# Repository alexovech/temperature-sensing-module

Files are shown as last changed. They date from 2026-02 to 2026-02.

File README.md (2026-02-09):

# Greenhouse Monitoring System – Temperature Sensing Module

Team of 4 students.  
My role: temperature sensing module design, multi-sensor integration, and 3D enclosure design.   
Designed and implemented an LM35-based temperature sensing module with analog signal conditioning, calibration, and hardware-level error detection.  
The project consists of two stages: a standalone temperature sensing module and system integration with enclosure.

---

## Overview

- **Full project description:** [Overview](docs/overview.md)
- **Skills Developed:** Designing operational amplifier circuit, sensor calibration and parameter identification, embedded system implementation in Arduino, 3D CAD modelling.
- **Features:** OpAmp-based gain and offset correction, Arduino ADC inverse mapping, sensor error detection, custom 3D-printed enclosure.
- **Technology:** Arduino, LM35 temperature sensor, LM741 operational amplifier, Resistors, OLED display, LEDs.
- **Simulation:** Analog part designed in [Multisim](schematic/multisim/Adder_with_divider_rule); Enclosure model designed in [Autodesk Fusion 360](schematic/cad).
- **Language:** C/C++ (Arduino).

---

# Stage 1 - Temperature Sensor

## Problem Statement

The LM35 temperature sensor provides a low-level output (~10 mV/°C).  
The Arduino ADC operates over a much higher voltage range: from 3 V to 5 V.  
Such a small sensor voltage results in poor ADC resolution and reduced measurement accuracy.  
To obtain valid and reliable temperature readings, the signal must be shifted and amplified into a suitable voltage range.  
This is achieved using LM741 operational amplifiers and resistive networks.

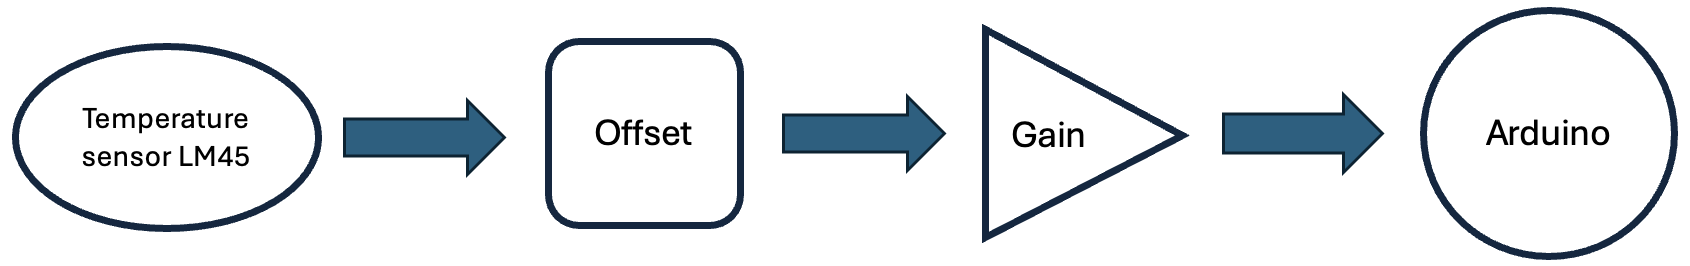
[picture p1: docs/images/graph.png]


## Design Demonstration

**Hardware Implementation**

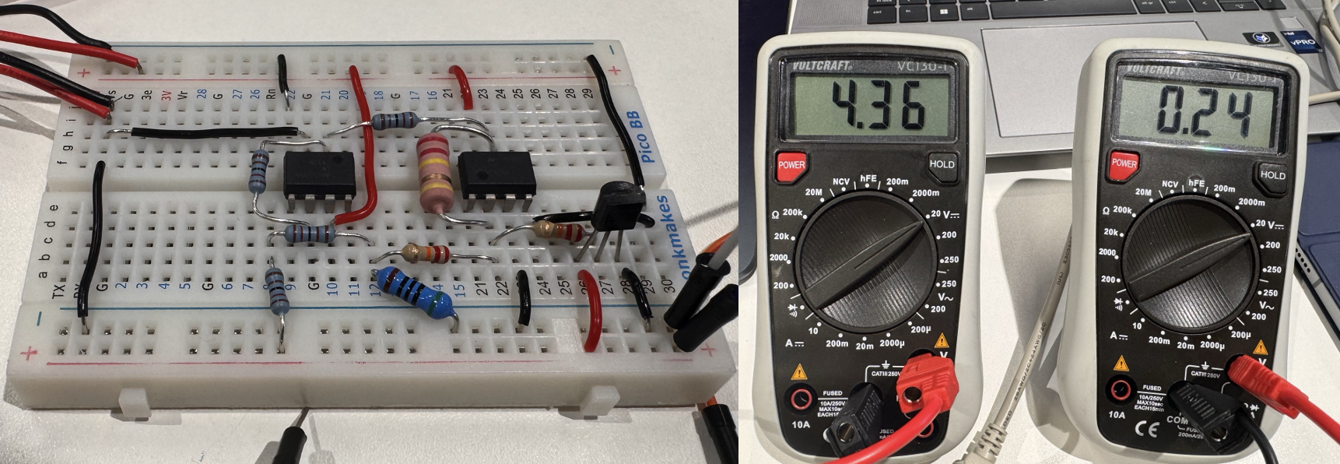
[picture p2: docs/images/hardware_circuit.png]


**Circuit in Multisim**

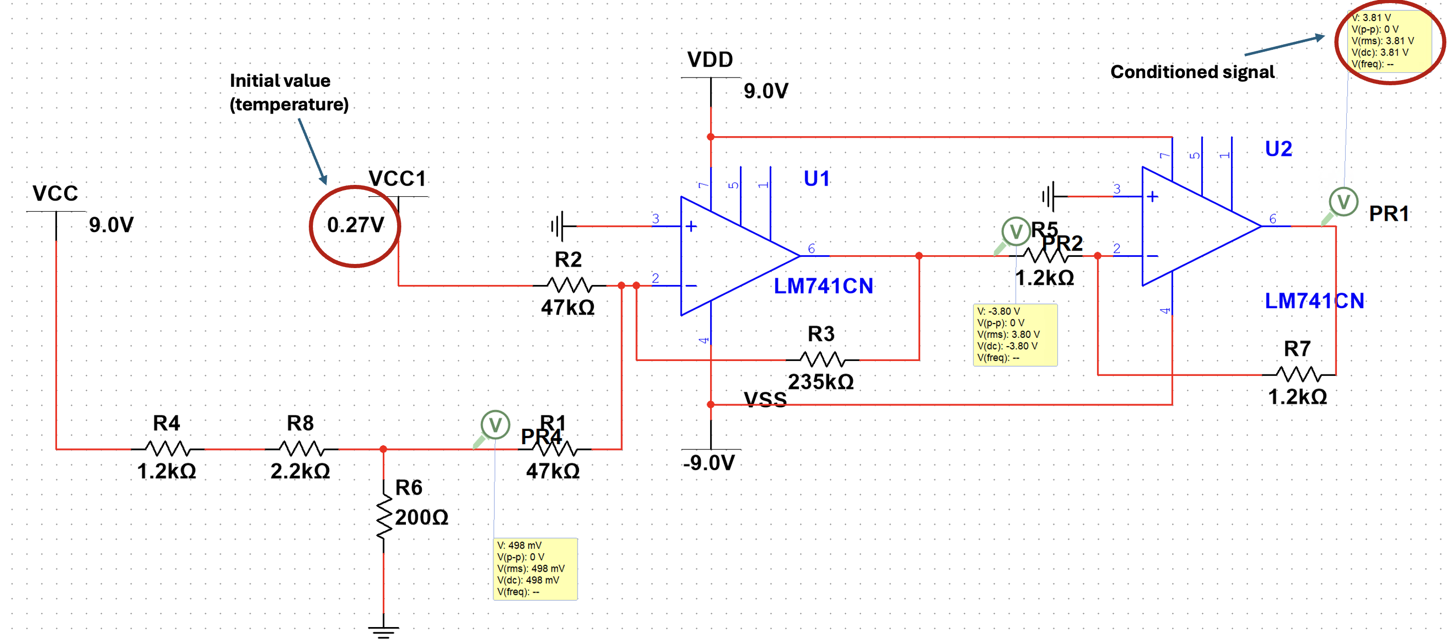
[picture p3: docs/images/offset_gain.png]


`Highlighted input and output voltage levels confirm correct signal conditioning before ADC conversion.`

## Calibration & Arduino Processing

At temperature extremes, the LM35 sensor output may deviate from its ideal linear behaviour, resulting in measurement offsets and scaling errors.
To improve accuracy, a linear calibration model was derived:  

`T = (Vsens − 0.051) / 0.008`

➡️ [View detailed calibration process here](docs/calibration.md)  

**Arduino Code** (➡️[View here](src/code_temp))   
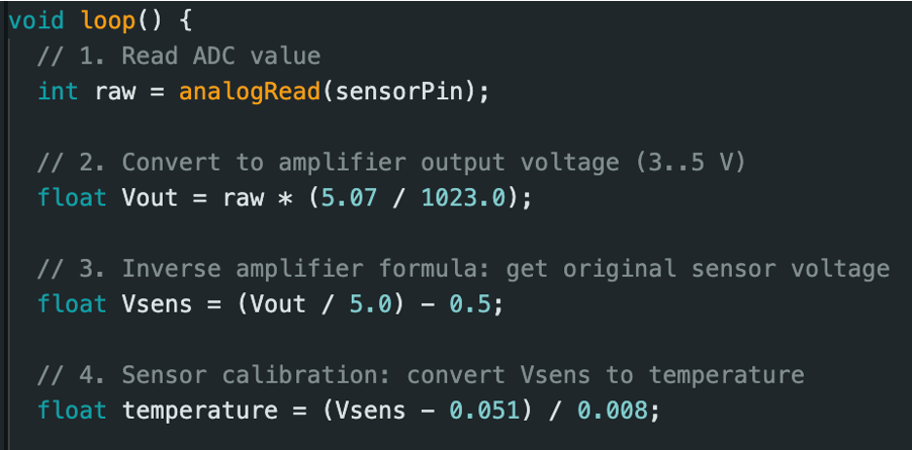
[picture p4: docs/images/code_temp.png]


`1. The ADC value is read and converted to the amplifier output voltage using a measured reference voltage.`  
`2. Next, the inverse gain and offset are applied to reconstruct the equivalent LM35 sensor voltage.`   
`3. Finally, the calibrated linear model is used to convert the sensor voltage into a temperature value.`

## Problem Solving Process

**Full list of challenges and solutions:** [Problems & Solutions](docs/problems_solutions.md)

**Example of handwritten notes:** 
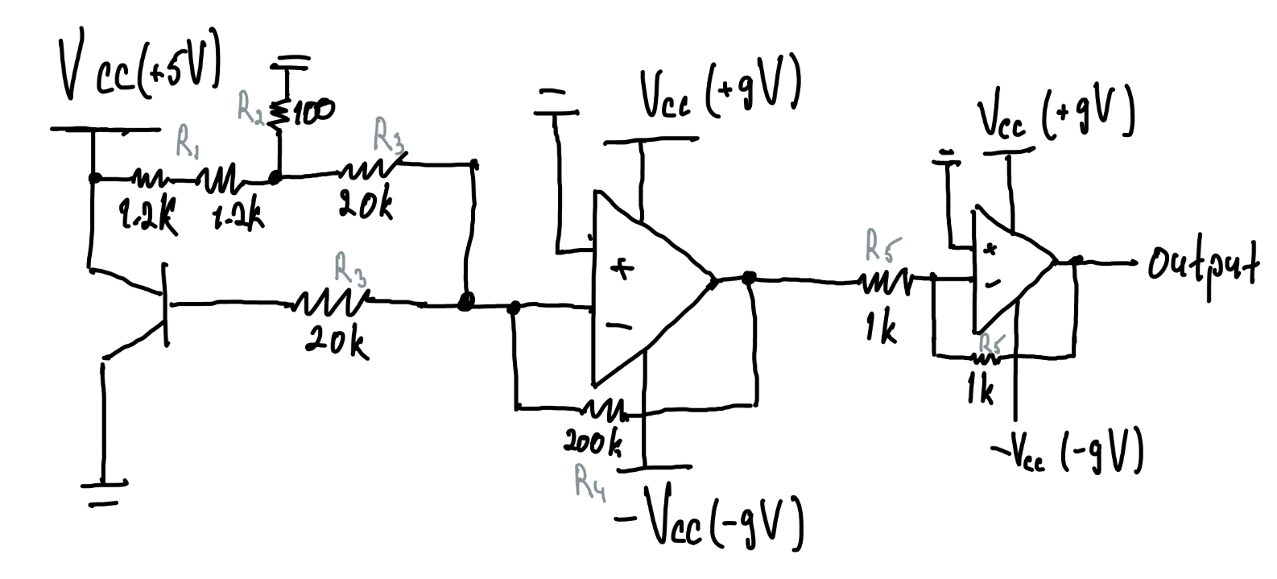
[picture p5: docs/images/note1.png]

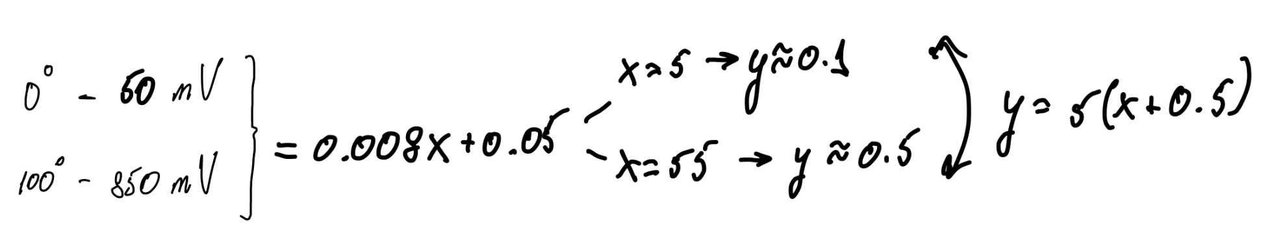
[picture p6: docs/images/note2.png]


---

# Stage 2 — System Integration & Enclosure

## Integration of Multiple Sensors

Each sensor processing block is integrated into a single [Arduino](src/all_sensors_pwr_rst_error) `loop()` and organised into clearly separated sections for each sensor. This approach keeps the overall code structure clear and easy to follow.  
Each block includes signal acquisition, conversion to physical units, and their own error detection function.

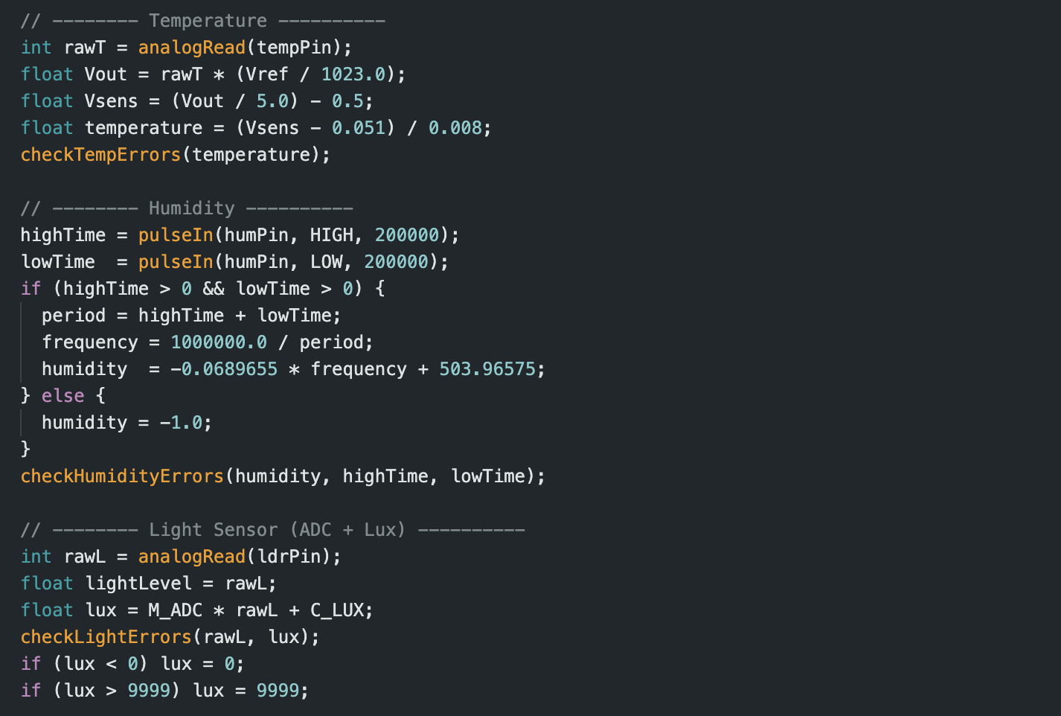
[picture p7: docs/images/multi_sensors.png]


## Hardware Error Detection

In real-world applications, sensor readings may become unreliable due to hardware-related issues.
These issues include disconnected sensors, short circuits, sudden signal changes caused by noise,
or a sensor becoming stuck at a constant value.

Instead of embedding error checks directly into the main logic, dedicated error-detection functions
were created for each sensor type.
When an error condition is detected, a corresponding LED indicator is activated to provide visual feedback.

**Temperature error detection snippet**
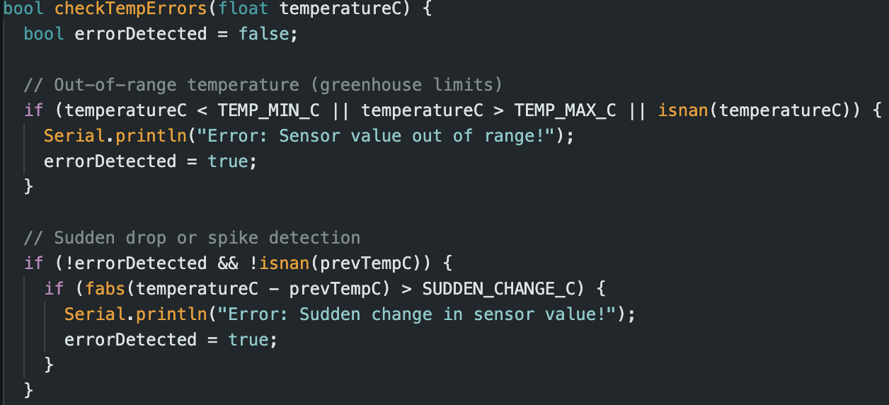
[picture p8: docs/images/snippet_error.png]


## Enclosure Design & Manufacturing

A custom enclosure was designed to house the Arduino, breadboard, OLED display, buzzer, and supporting circuitry.  
The enclosure was modelled in [Autodesk Fusion 360](schematic/cad) taking into account all components parameters to be correctly implemented into model design.  
One of the distinctive features is a latch mechanism incorporated for easy access for maintenance or debugging.
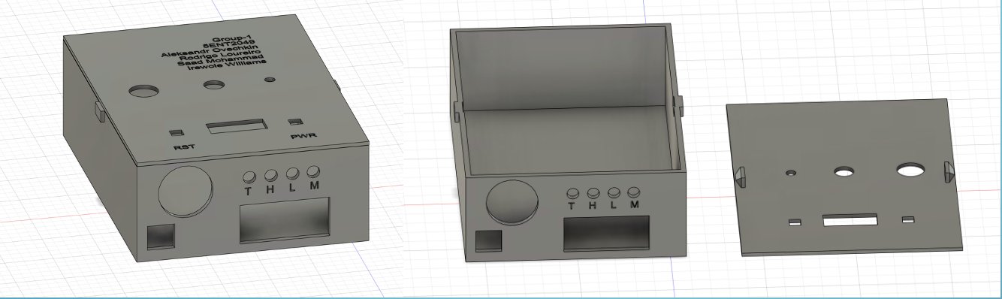
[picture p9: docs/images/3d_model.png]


The final design was manufactured using 3D printing and assembled as a complete physical system.
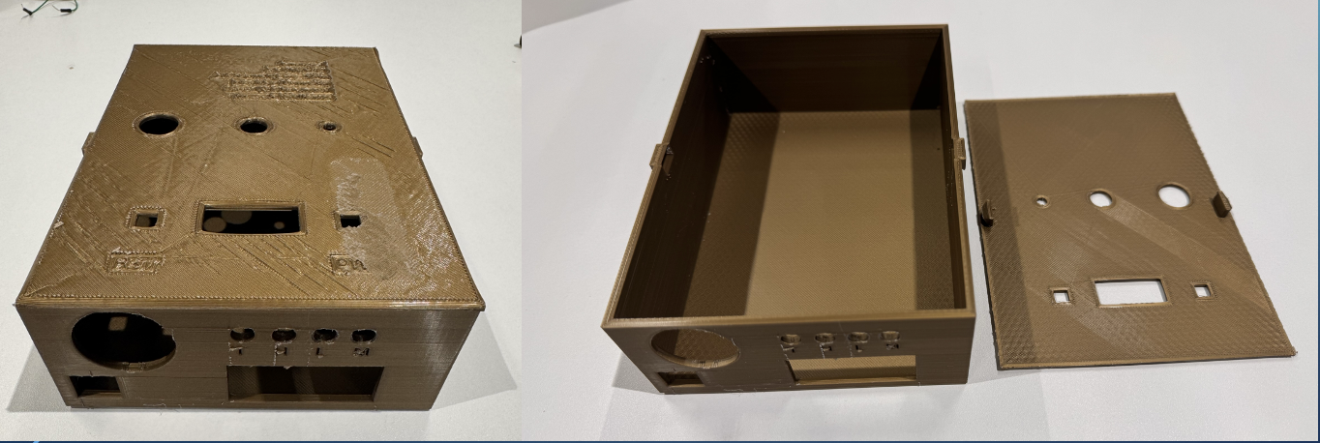
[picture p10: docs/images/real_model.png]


## Early System Demonstration



## Future Improvements

Although the current system meets all project requirements, several improvements could be implemented
to further enhance functionality, reliability, and scalability.

1. **Measurement Accuracy and Stability**
   - Replace the LM741 with a modern rail-to-rail operational amplifier with low input offset and single-supply operation.
   - This would eliminate the need for ±9 V supplies and reduce DC offset and bias current effects.

2. **Extended Calibration and Temperature Compensation**
   - Perform multi-point calibration across the temperature range instead of using only 0°C and 100°C reference points.
   - Implement lookup-table or polynomial correction in Arduino to improve accuracy over a wider range.

3. **Enhanced Error Detection**
   - Introduce adaptive thresholds for noise detection instead of fixed limits.
   - Automatically exclude invalid sensor readings from display and data transmission.
   - Add error flag logging for post-processing and analysis in MATLAB.

4. **Hardware and Enclosure Improvements**
   - Optimise the enclosure design to improve thermal airflow around the temperature sensor.
   - Add mounting points and cable strain relief for improved robustness and repeatable assembly.

5. **System Functionality Expansion**
   - Add wireless data transmission (Bluetooth or Wi-Fi) for remote monitoring and logging.

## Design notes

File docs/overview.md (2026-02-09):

## Introduction

This project is a Monitoring system for a greenhouse. The Monitoring device contains temperature, light, humidity, and ultrasonic sensors; the analogue outputs are converted into digital measurements for the Arduino UNO R3 and then display the values on an OLED using Adafruit library.

The importance of this device is to ensure that plants have the best possible environment to grow. Any faults will be detected and quickly warn the user. An encryption was applied to the display for security. A checksum function was also added so that the total value of all values given from readings was checked to see if it matched the machine's calculations.

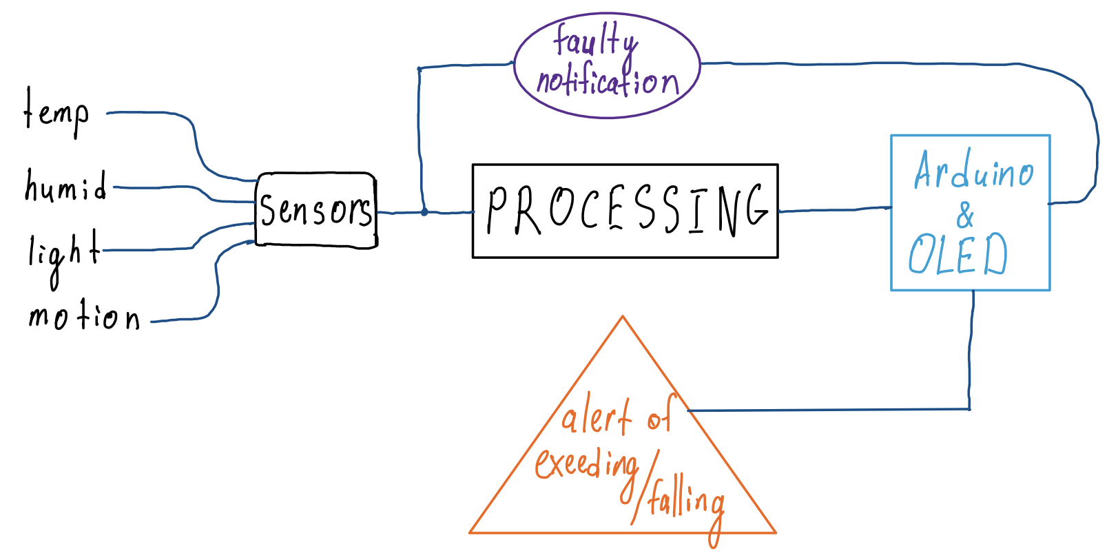
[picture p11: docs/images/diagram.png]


---

## Roles of Sensors

- The Humidity sensor was to ensure the humidity was not high to damage the plants.
- The Light sensor was to ensure the light in the greenhouse was at acceptable levels.
- The Temperature sensor was to ensure the temperature was not high or too low so the plants can grow properly.
- The Motion sensor was for security so that anyone approaching the greenhouse at a certain proximity has an alarm sound off when they get too close.

---

## Temperature Sensor

The principle of working temperature sensor includes converting the measured temperature into a proportional voltage output of approximately 10 mV/°C. To better understand and validate this behaviour, a simplified model of the temperature sensor was created. However, due to modelling limitations in Multisim, the sensor behaviour could only be reproduced using operational amplifiers.

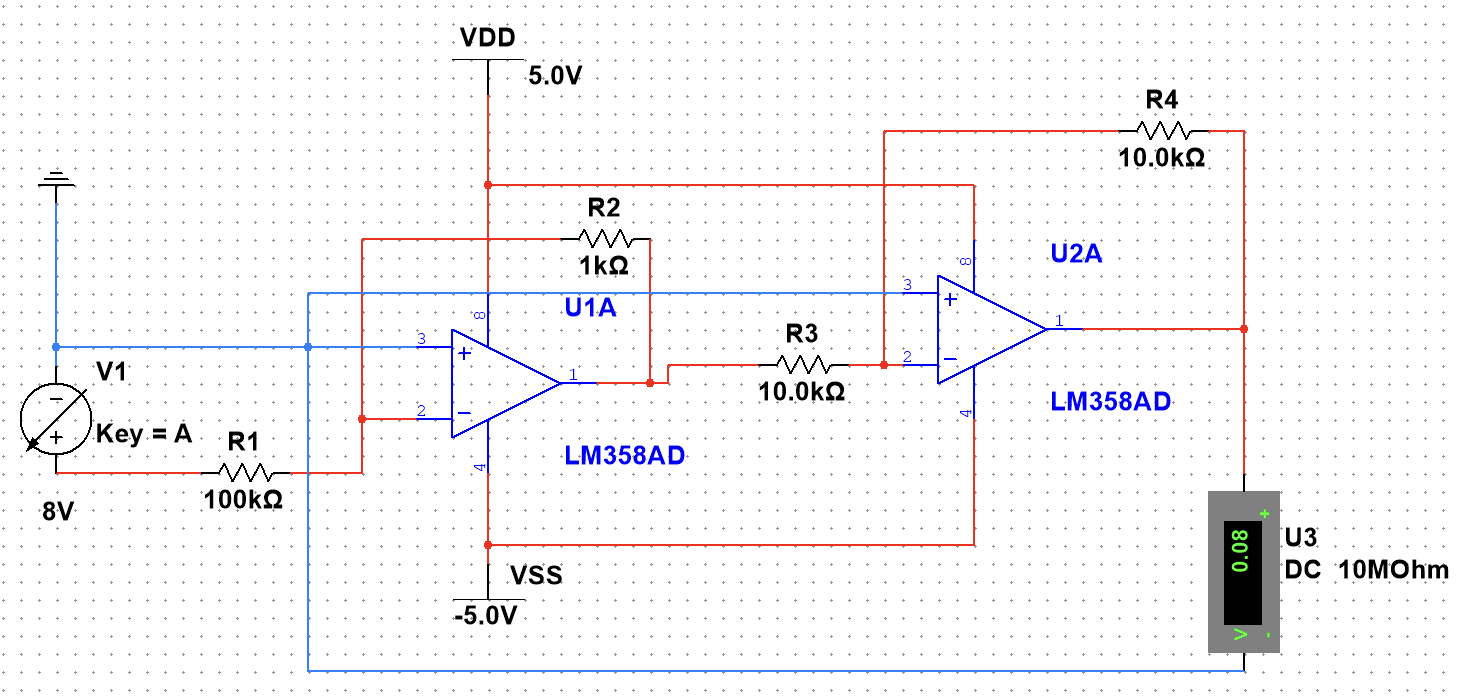
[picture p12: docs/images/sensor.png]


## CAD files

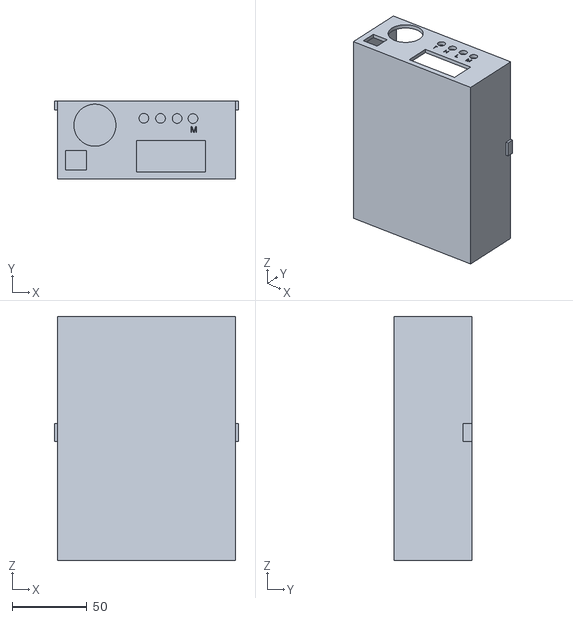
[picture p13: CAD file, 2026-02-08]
schematic/cad/Box.stl
123.0 x 52.0 x 163.0

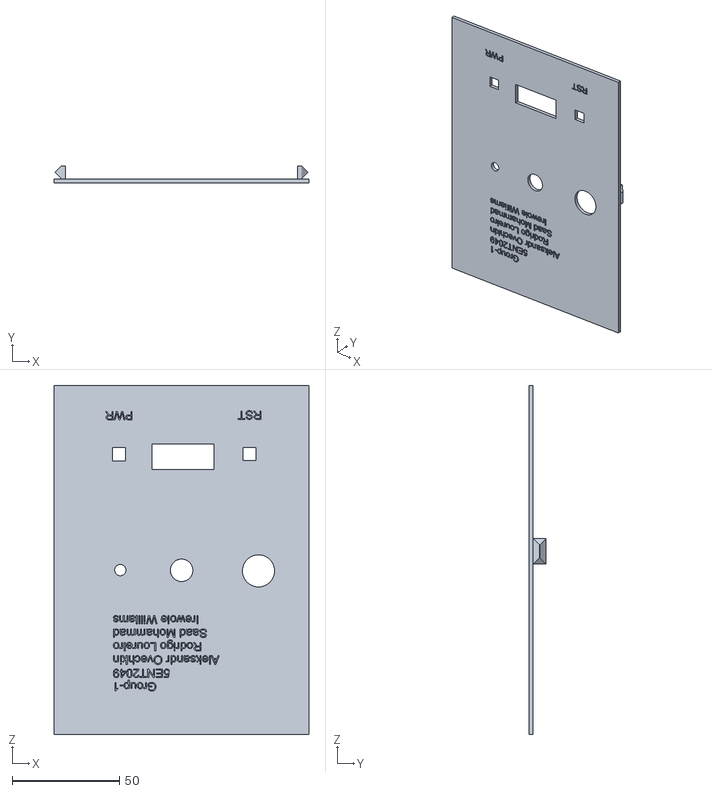
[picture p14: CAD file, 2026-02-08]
schematic/cad/Cover.stl
119.0 x 7.99 x 163.0

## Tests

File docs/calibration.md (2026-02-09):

## Purpose of calibration

The objective was to verify and confirm the accuracy of the output values, especially under non-standard conditions where the sensor may receive a greater or lesser load than expected. 
If the values do not match the simulation, a new linear relationship will be created, which will be required for the implementation to the Software module.

## Extreme Condition Testing

Initially, the sensor was placed in a low-temperature environment, which was measured using a non-contact infrared thermometer and was approximately 0 °C. 
In this experiment, any contact with the sensor that could emit additional heat was minimized, so the measurements were as accurate as possible. 
The result from the LM35 was 0.05 V, which was comparable to 5 °C.

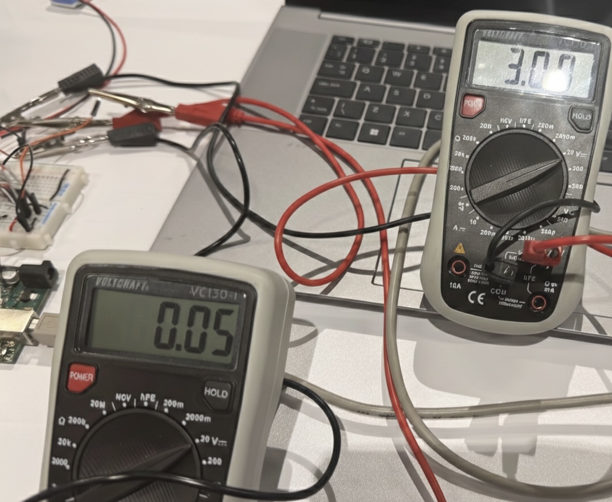
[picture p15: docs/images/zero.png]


In the next procedure, the tests were conducted at temperatures closer to the maximum values. 
In this case, a specific heater was used to accurately produce energy comparable to 100 °C. 
Under these results, the sensor readings showed 0.85 V, i.e. 85 °C.



Based on these results, a new linear relationship should be created, which will be used in the future to calibrate the sensor value to its ideal parameters. Excel was used to create the linear graph and obtain the linear equation. The accuracy of the temperature measurement module can be improved by making use of additional calibration points, a better operational amplifier, and a voltage reference.

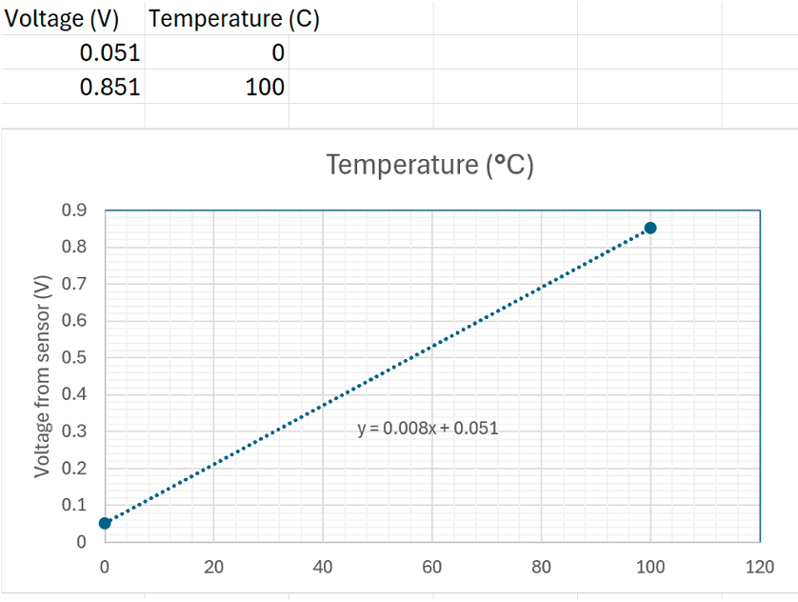
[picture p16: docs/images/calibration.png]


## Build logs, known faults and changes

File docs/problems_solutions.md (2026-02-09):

## Problem 1 — Operational Amplifier Topology Limitation

Due to component availability constraints, only LM741 operational amplifiers were provided for the analog front-end design. 
With this amplifier, voltage summation and offset generation can only be achieved using an inverting configuration.
As a result, the conditioned signal polarity was inverted after the first amplification stage.  

**Solution:**  
A second operational amplifier stage was introduced to restore the original signal polarity, resulting in a two-stage amplifier architecture.

---

## Problem 2 — Operational Amplifier Power Supply Requirements

Initially, the LM741 operational amplifiers were powered from the same 5 V supply as the Arduino system.
Under this configuration, the amplifier output exhibited incorrect gain behaviour and saturation effects.  

**Solution:**  
It was identified that the LM741 requires a higher supply voltage. Two 9 V batteries were introduced to provide a ±9 V dual supply configuration, enabling correct amplifier operation.

---

## Problem 3 — Mixed Power Supply Grounding Issue

After introducing the ±9 V supply for the operational amplifiers, the system still produced unstable and incorrect readings.
This issue was traced to the presence of multiple power supplies (±9 V for the amplifiers and 5 V for the Arduino and sensors) without a shared ground reference.  

**Solution:**  
The ground references of the ±9 V amplifier supply and the 5 V Arduino supply were connected to establish a common ground.
This resolved the instability and allowed consistent voltage measurements across the system.

---

## Problem 4 — ADC Conversion Scaling Error

Initial ADC-to-voltage conversion calculations assumed an ideal 5.0 V reference voltage for the Arduino ADC. 
However, measurements using a multimeter showed that the actual supply voltage was approximately 5.07 V.
This discrepancy introduced a systematic scaling error in the computed sensor voltage and temperature values.  

**Solution:**  
The measured reference voltage value was used in the ADC conversion formula within the Arduino code, improving the accuracy of the reconstructed sensor voltage.

---

## Problem 5 — Resistor Interaction Between Offset and Gain Networks

The offset generation network and the gain-setting network were not independent due to their shared connection to the ground reference. 
The resistor responsible for generating the voltage offset formed a voltage divider that shared a common node with the resistor used in the amplification stage.
Although one resistor was referenced to the real ground and the other to the virtual ground of the operational amplifier, both influenced the effective divider behaviour.

As a result, the expected offset voltage was not achieved, as the gain resistor began to load the offset network and modify the resulting voltage level.
Additionally, excessively large resistor values introduced further errors due to the input bias currents of the LM741 operational amplifier.

**Solution:**  
Resistor values were selected to balance minimal loading of the offset network and acceptable bias current effects.
The final configuration used 20 kΩ and 200 kΩ resistors, providing stable offset generation while maintaining accurate gain and minimising bias-induced voltage errors.

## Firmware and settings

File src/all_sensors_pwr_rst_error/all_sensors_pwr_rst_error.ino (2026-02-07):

#include <Wire.h>
#include <Adafruit_GFX.h>
#include <Adafruit_SSD1306.h>
#include <math.h>

// OLED setup
#define SCREEN_WIDTH 128
#define SCREEN_HEIGHT 32
#define OLED_RESET -1
#define SCREEN_ADDRESS 0x3C   // or 0x3D if needed

Adafruit_SSD1306 display(SCREEN_WIDTH, SCREEN_HEIGHT, &Wire, OLED_RESET);

// Pins
const int tempPin   = A0;
const int tempLedPin = 4;   // LED for temperature sensor
const int humPin    = 3;
const int humLedPin = 5;   // LED for humidity sensor
const int trigPin   = 9;
const int echoPin   = 10;
const int buzzerPin = 8;
const int ldrPin    = A1;   // same pin used for light sensor
const int lightLedPin = 6;   // LED for light sensor
const int resetBtnPin = 2;   // RESET button (active LOW, using INPUT_PULLUP)
const int powerBtnPin = 7;   // POWER button (active LOW, INPUT_PULLUP)

// Constants
const float Vref = 5.07; // temperature
const float TEMP_MIN_C = 15.0;
const float TEMP_MAX_C = 30.0;
const float SUDDEN_CHANGE_C = 3.0;
const float STUCK_DELTA_C   = 0.2;
const int   STUCK_COUNT_N   = 10;

const float M_ADC = -0.884784f;   // LDR , lux per ADC count
const float C_LUX = 919.134f;     // lux intercept
const float HUM_MIN_PCT = 20.0;
const float HUM_MAX_PCT = 90.0;
const float HUM_SUDDEN_DELTA = 10.0;  // % jump per sample
const float HUM_STUCK_DELTA  = 0.5;   // % minimal change considered "no change"
const int   HUM_STUCK_COUNT_N = 10;   // 10 cycles ~ 5 seconds (with delay(500))

const int   LIGHT_ADC_MIN = 5;        // near GND
const int   LIGHT_ADC_MAX = 1018;     // near VCC
const float LUX_MIN = 100.0;          // greenhouse lower limit
const float LUX_MAX = 9000.0;         // greenhouse upper limit
const int   LIGHT_SUDDEN_DELTA = 200; // ADC jump per sample
const int   LIGHT_STUCK_DELTA  = 3;   // minimal ADC change
const int   LIGHT_STUCK_COUNT_N = 10; // ~5 seconds

const float ULTRA_MIN_CM = 2.0; // MOTION
const float ULTRA_MAX_CM = 400.0;
const float ULTRA_SUDDEN_DELTA_CM = 15.0;
const float ULTRA_STUCK_DELTA_CM  = 0.5;   // tolerance for "no change"
const int   ULTRA_STUCK_COUNT_N   = 10;    // ~5 seconds (delay(500))

// Variables
float frequency = 0.0;
float humidity  = -1.0;
unsigned long highTime = 0;
unsigned long lowTime  = 0;
unsigned long period   = 0;
float prevTempC = NAN;
int stuckCounter = 0;
float prevHumidity = NAN;
int humStuckCounter = 0;
int prevRawL = -1;
int lightStuckCounter = 0;
float prevDistance = -1.0;
int ultraStuckCounter = 0;
bool ultrasonicError = false;
bool lastResetBtnState = HIGH;
unsigned long lastResetDebounceMs = 0;
const unsigned long RESET_DEBOUNCE_MS = 50;
bool systemEnabled = true;
bool lastPowerBtnState = HIGH;
unsigned long lastPowerDebounceMs = 0;
const unsigned long POWER_DEBOUNCE_MS = 50;

long duration = 0;
float distanceCm = -1.0;

// Function for TEMPERATURE error detection
bool checkTempErrors(float temperatureC) {
  bool errorDetected = false;

  // Out-of-range temperature (greenhouse limits)
  if (temperatureC < TEMP_MIN_C || temperatureC > TEMP_MAX_C || isnan(temperatureC)) {
    Serial.println("Error: Sensor value out of range!");
    errorDetected = true;
  }

  // Sudden drop or spike detection
  if (!errorDetected && !isnan(prevTempC)) {
    if (fabs(temperatureC - prevTempC) > SUDDEN_CHANGE_C) {
      Serial.println("Error: Sudden change in sensor value!");
      errorDetected = true;
    }
  }

  // Sensor stuck at constant value
  if (!errorDetected && !isnan(prevTempC)) {
    if (fabs(temperatureC - prevTempC) < STUCK_DELTA_C) {
      stuckCounter++;
    } else {
      stuckCounter = 0;
    }

    if (stuckCounter >= STUCK_COUNT_N) {
      Serial.println("Error: Sensor stuck at constant value!");
      errorDetected = true;
    }
  } else {
    stuckCounter = 0;
  }

  // LED indication for temperature sensor
  digitalWrite(tempLedPin, errorDetected ? HIGH : LOW);

  // Store previous temperature value
  prevTempC = temperatureC;

  return errorDetected;
}

// Function for HUMIDITY error detection
bool checkHumidityErrors(float humidityPct, unsigned long highTimeUs, unsigned long lowTimeUs) {
  bool errorDetected = false;

  // Error 1: No signal / disconnected (timeout)
  if (highTimeUs == 0 || lowTimeUs == 0 || isnan(humidityPct)) {
    Serial.println("Error: No humidity signal!");
    errorDetected = true;
  }

  // Error 2: Out of range humidity (greenhouse limits)
  if (!errorDetected) {
    if (humidityPct < HUM_MIN_PCT || humidityPct > HUM_MAX_PCT) {
      Serial.println("Error: Humidity value out of range!");
      errorDetected = true;
    }
  }

  // Error 3: Sudden change (noise / glitch)
  if (!errorDetected && !isnan(prevHumidity)) {
    if (fabs(humidityPct - prevHumidity) > HUM_SUDDEN_DELTA) {
      Serial.println("Error: Sudden change in humidity value!");
      errorDetected = true;
    }
  }

  // Error 4: Stuck at constant value
  if (!errorDetected && !isnan(prevHumidity)) {
    if (fabs(humidityPct - prevHumidity) < HUM_STUCK_DELTA) humStuckCounter++;
    else humStuckCounter = 0;

    if (humStuckCounter >= HUM_STUCK_COUNT_N) {
      Serial.println("Error: Humidity sensor stuck at constant value!");
      errorDetected = true;
    }
  } else {
    humStuckCounter = 0;
  }

  // LED indication for humidity sensor
  digitalWrite(humLedPin, errorDetected ? HIGH : LOW);

  // Store previous humidity value
  prevHumidity = humidityPct;

  return errorDetected;
}

// Function for LIGHT error detection
bool checkLightErrors(int rawL, float luxValue) {
  bool errorDetected = false;

  // Error 1: Disconnected or short circuit
  if (rawL <= LIGHT_ADC_MIN || rawL >= LIGHT_ADC_MAX) {
    Serial.println("Error: Light sensor disconnected or shorted!");
    errorDetected = true;
  }

  // Error 2: Out of expected light range
  if (!errorDetected) {
    if (luxValue < LUX_MIN || luxValue > LUX_MAX) {
      Serial.println("Error: Light level out of range!");
      errorDetected = true;
    }
  }

  // Error 3: Sudden change (noise)
  if (!errorDetected && prevRawL >= 0) {
    if (abs(rawL - prevRawL) > LIGHT_SUDDEN_DELTA) {
      Serial.println("Error: Sudden change in light level!");
      errorDetected = true;
    }
  }

  // Error 4: Sensor stuck
  if (!errorDetected && prevRawL >= 0) {
    if (abs(rawL - prevRawL) < LIGHT_STUCK_DELTA) {
      lightStuckCounter++;
    } else {
      lightStuckCounter = 0;
    }

    if (lightStuckCounter >= LIGHT_STUCK_COUNT_N) {
      Serial.println("Error: Light sensor stuck at constant value!");
      errorDetected = true;
    }
  } else {
    lightStuckCounter = 0;
  }

  // LED indication
  digitalWrite(lightLedPin, errorDetected ? HIGH : LOW);

  // Store previous ADC value
  prevRawL = rawL;

  return errorDetected;
}


// Function for MOTION error detection
bool checkUltrasonicErrors(float distanceCmValue) {
  bool errorDetected = false;

  // Error 2: Out of valid range (HC-SR04 typical range)
  if (distanceCmValue < ULTRA_MIN_CM || distanceCmValue > ULTRA_MAX_CM) {
    Serial.println("Error: Distance value out of valid range!");
    errorDetected = true;
  }

  // Error 3: Sudden spike detection
  if (!errorDetected && prevDistance > 0) {
    if (fabs(distanceCmValue - prevDistance) > ULTRA_SUDDEN_DELTA_CM) {
      Serial.println("Error: Sudden spike detected in ultrasonic reading!");
      errorDetected = true;
    }
  }

  // Error 4: Stuck / flat-line detection (with tolerance)
  if (!errorDetected && prevDistance > 0) {
    if (fabs(distanceCmValue - prevDistance) < ULTRA_STUCK_DELTA_CM) {
      ultraStuckCounter++;
      if (ultraStuckCounter >= ULTRA_STUCK_COUNT_N) {
        Serial.println("Error: Ultrasonic sensor flat-line detected!");
        errorDetected = true;
      }
    } else {
      ultraStuckCounter = 0;
    }
  } else {
    ultraStuckCounter = 0;
  }

  // Store previous value
  prevDistance = distanceCmValue;

  return errorDetected;
}

// Function for RST button
void resetAllErrors() {
  // Turn off all error LEDs
  digitalWrite(tempLedPin, LOW);
  digitalWrite(humLedPin, LOW);
  digitalWrite(lightLedPin, LOW);

  // Clear error flags
  ultrasonicError = false;

  // Reset history values (prevents false sudden/stuck after reset)
  prevTempC = NAN;
  prevHumidity = NAN;
  prevRawL = -1;
  prevDistance = -1.0;

  // Reset counters
  stuckCounter = 0;
  humStuckCounter = 0;
  lightStuckCounter = 0;
  ultraStuckCounter = 0;

  // Safety: turn off buzzer
  digitalWrite(buzzerPin, LOW);
}

// Function for ON PWR button
void powerOffSystem() {
  systemEnabled = false;

  // Turn off outputs
  digitalWrite(tempLedPin, LOW);
  digitalWrite(humLedPin, LOW);
  digitalWrite(lightLedPin, LOW);
  digitalWrite(buzzerPin, LOW);

  // Turn off OLED
  display.clearDisplay();
  display.display();
  display.ssd1306_command(SSD1306_DISPLAYOFF);
}

// Function for OFF PWR button
void powerOnSystem() {
  systemEnabled = true;

  // Turn on OLED
  display.ssd1306_command(SSD1306_DISPLAYON);

  // Reset error states on power-up
  resetAllErrors();
}

void setup() {
  Serial.begin(9600);

  pinMode(humPin, INPUT);
  pinMode(tempLedPin, OUTPUT);
  digitalWrite(tempLedPin, LOW);
  pinMode(trigPin, OUTPUT);
  pinMode(humLedPin, OUTPUT);
  digitalWrite(humLedPin, LOW);
  pinMode(echoPin, INPUT);
  pinMode(buzzerPin, OUTPUT);
  digitalWrite(buzzerPin, LOW);
  pinMode(lightLedPin, OUTPUT);
  digitalWrite(lightLedPin, LOW);
  pinMode(resetBtnPin, INPUT_PULLUP);
  pinMode(powerBtnPin, INPUT_PULLUP);
  
  

  if (!display.begin(SSD1306_SWITCHCAPVCC, SCREEN_ADDRESS)) {
    while (1) {
      Serial.println("OLED fail");
      delay(1000);
    }
  }

  display.clearDisplay();
  display.setTextSize(1);
  display.setTextColor(SSD1306_WHITE);
  display.setCursor(0, 0);
  display.println("System ready");
  display.display();
  delay(1000);
}

void loop() {
  bool reading = digitalRead(resetBtnPin);
if (reading != lastResetBtnState) {
  lastResetDebounceMs = millis();
}
if ((millis() - lastResetDebounceMs) > RESET_DEBOUNCE_MS) {
  // Button pressed (active LOW)
  if (lastResetBtnState == HIGH && reading == LOW) {
    resetAllErrors();
  }
}
lastResetBtnState = reading;

bool powerReading = digitalRead(powerBtnPin);
if (powerReading != lastPowerBtnState) {
  lastPowerDebounceMs = millis();
}
if ((millis() - lastPowerDebounceMs) > POWER_DEBOUNCE_MS) {
  // Button pressed (active LOW)
  if (lastPowerBtnState == HIGH && powerReading == LOW) {
    if (systemEnabled) {
      powerOffSystem();
    } else {
      powerOnSystem();
    }
  }
}
lastPowerBtnState = powerReading;

if (!systemEnabled) {
  delay(100);
  return;
}


  // -------- Temperature ----------
  int rawT = analogRead(tempPin);
  float Vout = rawT * (Vref / 1023.0);
  float Vsens = (Vout / 5.0) - 0.5;
  float temperature = (Vsens - 0.051) / 0.008;
  checkTempErrors(temperature);

  // -------- Humidity ----------
  highTime = pulseIn(humPin, HIGH, 200000);
  lowTime  = pulseIn(humPin, LOW, 200000);
  if (highTime > 0 && lowTime > 0) {
    period = highTime + lowTime;
    frequency = 1000000.0 / period;
    humidity  = -0.0689655 * frequency + 503.96575;
  } else {
    humidity = -1.0;
  }
  checkHumidityErrors(humidity, highTime, lowTime);

  // -------- Distance ----------
digitalWrite(trigPin, LOW);
delayMicroseconds(2);
digitalWrite(trigPin, HIGH);
delayMicroseconds(10);
digitalWrite(trigPin, LOW);

duration = pulseIn(echoPin, HIGH, 30000UL);

// Error 1: No echo received (timeout)
if (duration == 0) {
  ultrasonicError = true;
  distanceCm = -1.0;
  Serial.println("Error: No echo received (sensor disconnected or out of range)");
} else {
  distanceCm = duration * 0.034f / 2.0f;
  ultrasonicError = checkUltrasonicErrors(distanceCm);
}

// Buzzer warning only when there is NO sensor error
if (!ultrasonicError && distanceCm > 0 && distanceCm <= 5.0) {
  digitalWrite(buzzerPin, HIGH);
} else {
  digitalWrite(buzzerPin, LOW);
}

  // -------- Light Sensor (ADC + Lux) ----------
  int rawL = analogRead(ldrPin);
  float lightLevel = rawL;
  float lux = M_ADC * rawL + C_LUX;
  checkLightErrors(rawL, lux);
  if (lux < 0) lux = 0;
  if (lux > 9999) lux = 9999;

  // -------- Serial Output ----------
  Serial.print(humidity,1);    Serial.print(",");
  Serial.print(temperature,1); Serial.print(",");
  Serial.print(distanceCm,1);  Serial.print(",");
  Serial.print(lightLevel);    Serial.print(",");
  Serial.println(lux,1);

  // -------- Display ----------
  display.clearDisplay();
  display.setTextSize(1);

  display.setCursor(0, 0);
  display.print("Hum: ");
  if (humidity < 0) display.print("N/A");
  else { display.print(humidity, 1); display.print("%"); }

  display.setCursor(0, 10);
  display.print("Temp: ");
  display.print(temperature, 1);
  display.print("C");

  display.setCursor(0, 20);
  display.print("Dist: ");
  if (distanceCm < 0) display.print("N/A");
  else display.print(distanceCm, 1);
  display.print("cm");

  display.setCursor(70, 20);
  display.print("Lux:");
  display.print((int)lux);

  display.display();
  delay(500);
}

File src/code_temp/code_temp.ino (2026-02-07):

#include <Wire.h>
#include <Adafruit_GFX.h>
#include <Adafruit_SSD1306.h>

const int sensorPin = A0;

// OLED parameters
#define SCREEN_WIDTH 128
#define SCREEN_HEIGHT 32   // use 64 if you have a 128x64 display
#define OLED_RESET    -1   // reset not used on I2C OLED
Adafruit_SSD1306 display(SCREEN_WIDTH, SCREEN_HEIGHT, &Wire, OLED_RESET);

void setup() {
  Serial.begin(9600);

  // Initialize OLED
  if (!display.begin(SSD1306_SWITCHCAPVCC, 0x3C)) { // I2C address 0x3C is typical
    // If display is not found, stay here
    while (true) {
      Serial.println("SSD1306 allocation failed");
      delay(1000);
    }
  }

  display.clearDisplay();
  display.setTextColor(SSD1306_WHITE);
  display.setTextSize(1);
  display.setCursor(0, 0);
  display.println("Temp module start");
  display.display();
  delay(1000);
}

void loop() {
  // 1. Read ADC value
  int raw = analogRead(sensorPin);

  // 2. Convert to amplifier output voltage (3..5 V)
  float Vout = raw * (5.07 / 1023.0);

  // 3. Inverse amplifier formula: get original sensor voltage
  float Vsens = (Vout / 5.0) - 0.5;

  // 4. Sensor calibration: convert Vsens to temperature
  float temperature = (Vsens - 0.051) / 0.008;



  // ----- Serial output (for debugging) -----
  Serial.print("Vout = ");
  Serial.print(Vout, 3);
  Serial.print(" V | Temperature = ");
  Serial.print(temperature, 2);
  Serial.println(" C");

  // ----- OLED output -----
  display.clearDisplay();
  display.setTextSize(2);

  display.setCursor(0, 0);
  display.print("V:");
  display.print(Vout, 2);
  display.println("V");

  display.setCursor(0, 18); 
  display.print("T:");
  display.print(temperature, 1);
  display.println("C");

  display.display();

  delay(1000);  
}
